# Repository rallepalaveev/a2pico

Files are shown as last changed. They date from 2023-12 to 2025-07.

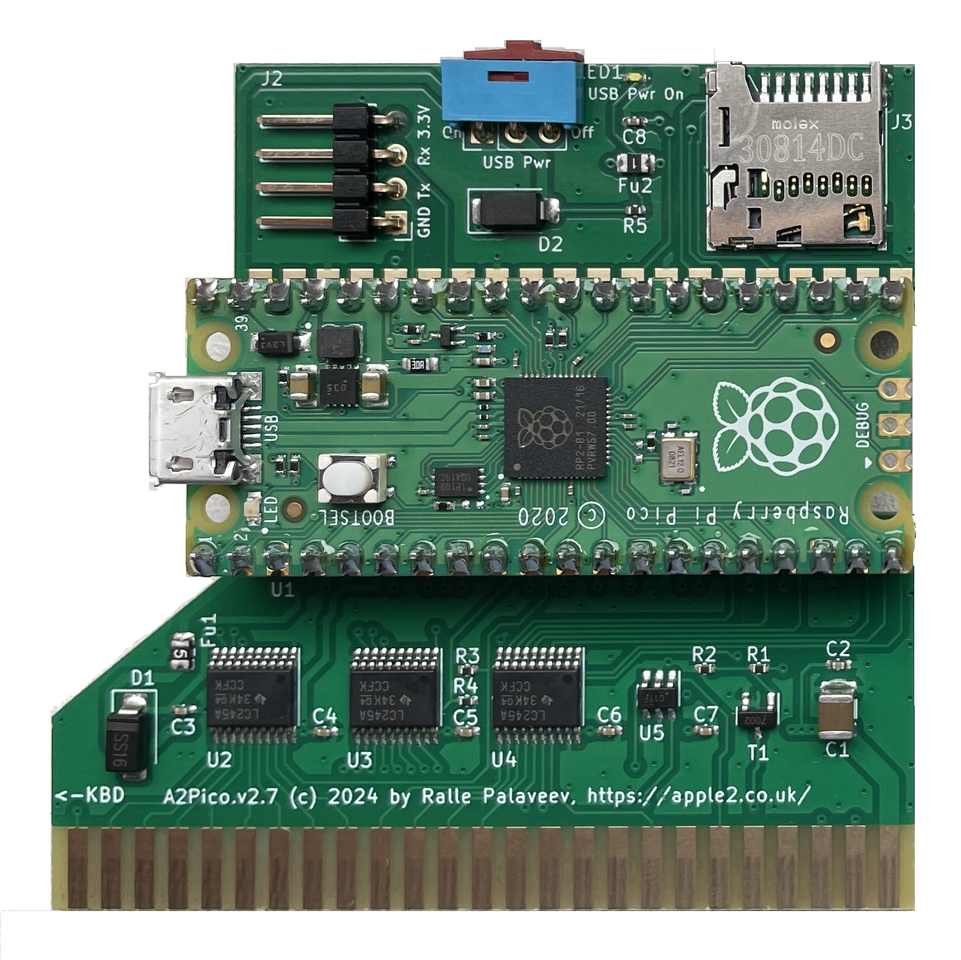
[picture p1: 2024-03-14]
A2Pico.v2.7/A2Pico.v2.7.png

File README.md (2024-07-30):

# A2Pico Reference Hardware

This repository is the home of the A2Pico reference hardware. Please refer to the upstream repository at https://github.com/oliverschmidt/a2pico for general information on A2Pico.

## Hardware Revision History

Version 1.4 is the innitial design with 3x 74LVC245 and 1x 74HC08 to prove the concept. However it is obsolete as it does not switch off the Expansion ROM ($C800-$CFFF), which is always available and could cause data bus conlisions if used with other cards that use this memory space.

Version 1.5 switches off the Expansion ROM ($C800-$CFFF) when $CFFF is accessed or when reset is issued, and switches it back on again when the slot memory is accessed (IOSelect).

Version 1.6 combines 3 of the logic chips into a PLD. 74LS08, 74LS133 and 74LS02 are replaced by ATF22V10.

The RPI usage is as follows:

| GPIO | Usage |
|:---|:---|
| 0 |  UART TX  |
| 1 |  UART RX  |
| 2 - 13  | A0 - A11  |
| 14 | R/W |
| 15 - 22 | D0 - D7 |
| 26 | ENBL |
| 27 | IRQ |
| 28 | RES |

Version "n" has support for a MicroSD card with **no** ExtROM capability.

The RPI usage of the "n" versions is as follows:

| GPIO | Usage |
|:---|:---|
| 0 |  SPI RX |
| 1 |  SPI CSn  |
| 2 |  SPI SCK  |
| 3 |  SPI TX |
| 4 |  NMI |
| 5 - 12  | A0 - A7 |
| 13 | DEVSEL |
| 14 | R/W |
| 15 - 22 | D0 - D7 |
| 26 | ENBL |
| 27 |  IRQ |
| 28 |  RES |

Version 1.7 is a direct successor of v1.4. Changes are replacing the 7408 by a 7411, data direction is controlled now by the Raspberry Pi Pico, which allows for all memory locations to be emulated, ENBL has an option to be is driven by a voltage divider for minimum latency, a USB "back power" option is included.

The RPI usage is as follows:

| GPIO | Usage |
|:---|:---|
| 0 |  UART TX  |
| 1 |  DATA dir |
| 2 - 13  | A0 - A11  |
| 14 | R/W |
| 15 - 22 | D0 - D7 |
| 26 | ENBL |
| 27 | IRQ |
| 28 | RES |

Versions 2.4 and 2.5 are a new hardware variant of v1.7 - TH and SMD respectively. The major change is that A0-7 and D0-7 are multiplexed and an SD card interface is added.
The RPI usage is as follows:

| GPIO | Usage |
|:---|:---|
| 0 |  UART Tx  |
| 1 |  UART Rx  |
| 2 |  ENBL |
| 3 - 10  | AD0 - AD7 |
| 11 - 14 | A8 - A11  |
| 15 | R/W |
| 16 | PHI1 |
| 17 | RES |
| 18 | IRQ |
| 19 | CMD |
| 20 | DAT0 |
| 21 | DAT3 |
| 22 | CLK |
| 26 | AL-OE |
| 27 | D-OE |
| 28 | DDIR |

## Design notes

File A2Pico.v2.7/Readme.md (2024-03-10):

A2Pico Version 2.7 is a follow-up of 2.5 with some small changes - changed form factor, added USB power slide switch, added USB power LED.

The RPI usage is as follows:

| GPIO | Usage |
|:---|:---|
| 0 |  UART Tx  |
| 1 |  UART Rx  |
| 2 |  ENBL |
| 3 - 10  | AD0 - AD7 |
| 11 - 14 | A8 - A11  |
| 15 | R/W |
| 16 | Ф1 |
| 17 | RES |
| 18 | IRQ |
| 19 | CMD |
| 20 | DAT0 |
| 21 | DAT3 |
| 22 | CLK |
| 26 | AL-OE |
| 27 | D-OE |
| 28 | DDIR |

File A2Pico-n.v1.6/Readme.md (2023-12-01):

This is a HW implementation with support for a MicroSD card and **no** ExtROM capability.

The pinout of the "n" versions is as follows:

| GPIO | Usage |
|:---|:---|
| 0 |  SPI RX |
| 1 |  SPI CSn  |
| 2 |  SPI SCK  |
| 3 |  SPI TX |
| 4 |  NMI |
| 5 - 12  | A0 - A7 |
| 13 | DEVSEL |
| 14 | R/W |
| 15 - 22 | D0 - D7 |
| 26 | ENBL |
| 27 |  IRQ |
| 28 |  RES |

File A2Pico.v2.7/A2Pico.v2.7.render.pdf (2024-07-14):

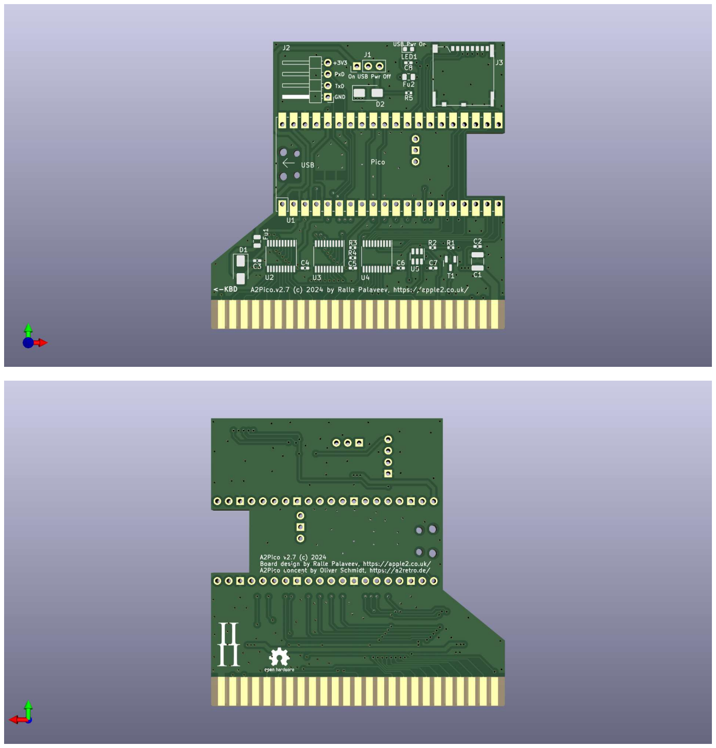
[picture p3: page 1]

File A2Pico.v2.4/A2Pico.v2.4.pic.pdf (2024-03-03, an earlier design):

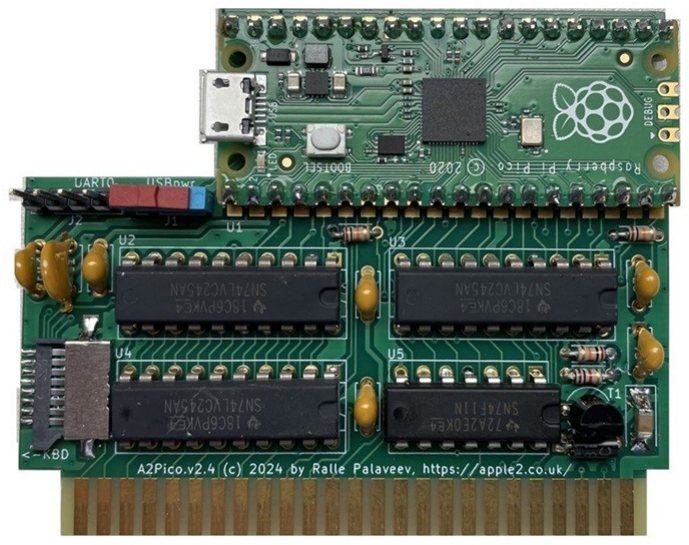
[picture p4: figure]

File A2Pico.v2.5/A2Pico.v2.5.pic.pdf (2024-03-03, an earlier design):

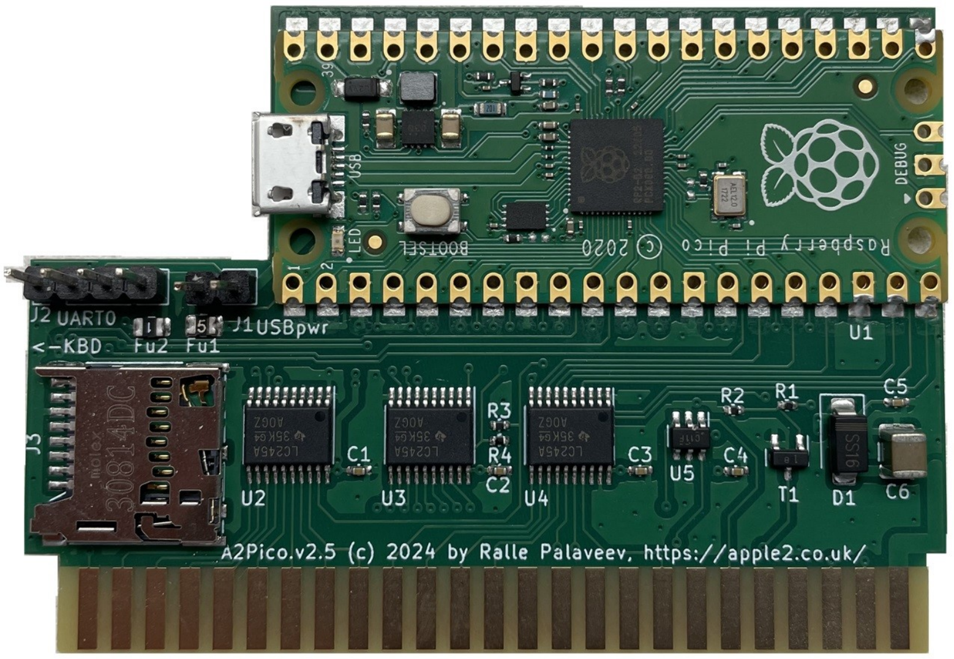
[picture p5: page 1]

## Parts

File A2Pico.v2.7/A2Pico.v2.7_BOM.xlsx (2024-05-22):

Comment | Designator | Footprint | JLCPCB Part #（optional）
10V 100uF X5R ±20% 1210 Multilayer Ceramic Capacitors MLCC - SMD/SMT ROHS | C1 | 1210 | C386065
16V 100nF X7R ±10% 0402 Multilayer Ceramic Capacitors MLCC - SMD/SMT ROHS | C2,C3,C4,C5,C6,C7,C8 | 0402 | C1525
1K | R1,R5 | 0402 | C11702
10K | R2,R3,R4 | 0402 | C25744
1.28mm Gold Deck MicroSD card (TF card) Self bomb SMD SD Card Connectors ROHS | J3 | SMD | C428492
3A Straight Square Pins 2.54mm 6mm -40℃~+105℃ 1 2 3mm 2.54mm Blac | J1 | PinHeader_1x02_P2.54mm_Vertical | C492401
3A Right-Angle Square Pins 2.5mm 4P 6mm | J2 | PinHeader_1x04_P2.54mm_Vertical | C2829875
6V 500mA Resettable Fuse | Fu1 | 0805-50 | C782729
6V 100mA Resettable Fuse | Fu2 | 0805 | C20975
SS16 SBD | D1,D2 | SMA(DO-214AC) | C908233
BS170F-BV | T1 | SOT-23 | C558098
Raspberry Pi PICO | U1 |  | C7203002
SN74LVC245APWR | U2,U3,U4 | TSSOP-20 | C7848
SN74LVC1G11DBVR | U5 | SOT-23-6 | C22046
White LED | LED1 | 0402 | C6848499

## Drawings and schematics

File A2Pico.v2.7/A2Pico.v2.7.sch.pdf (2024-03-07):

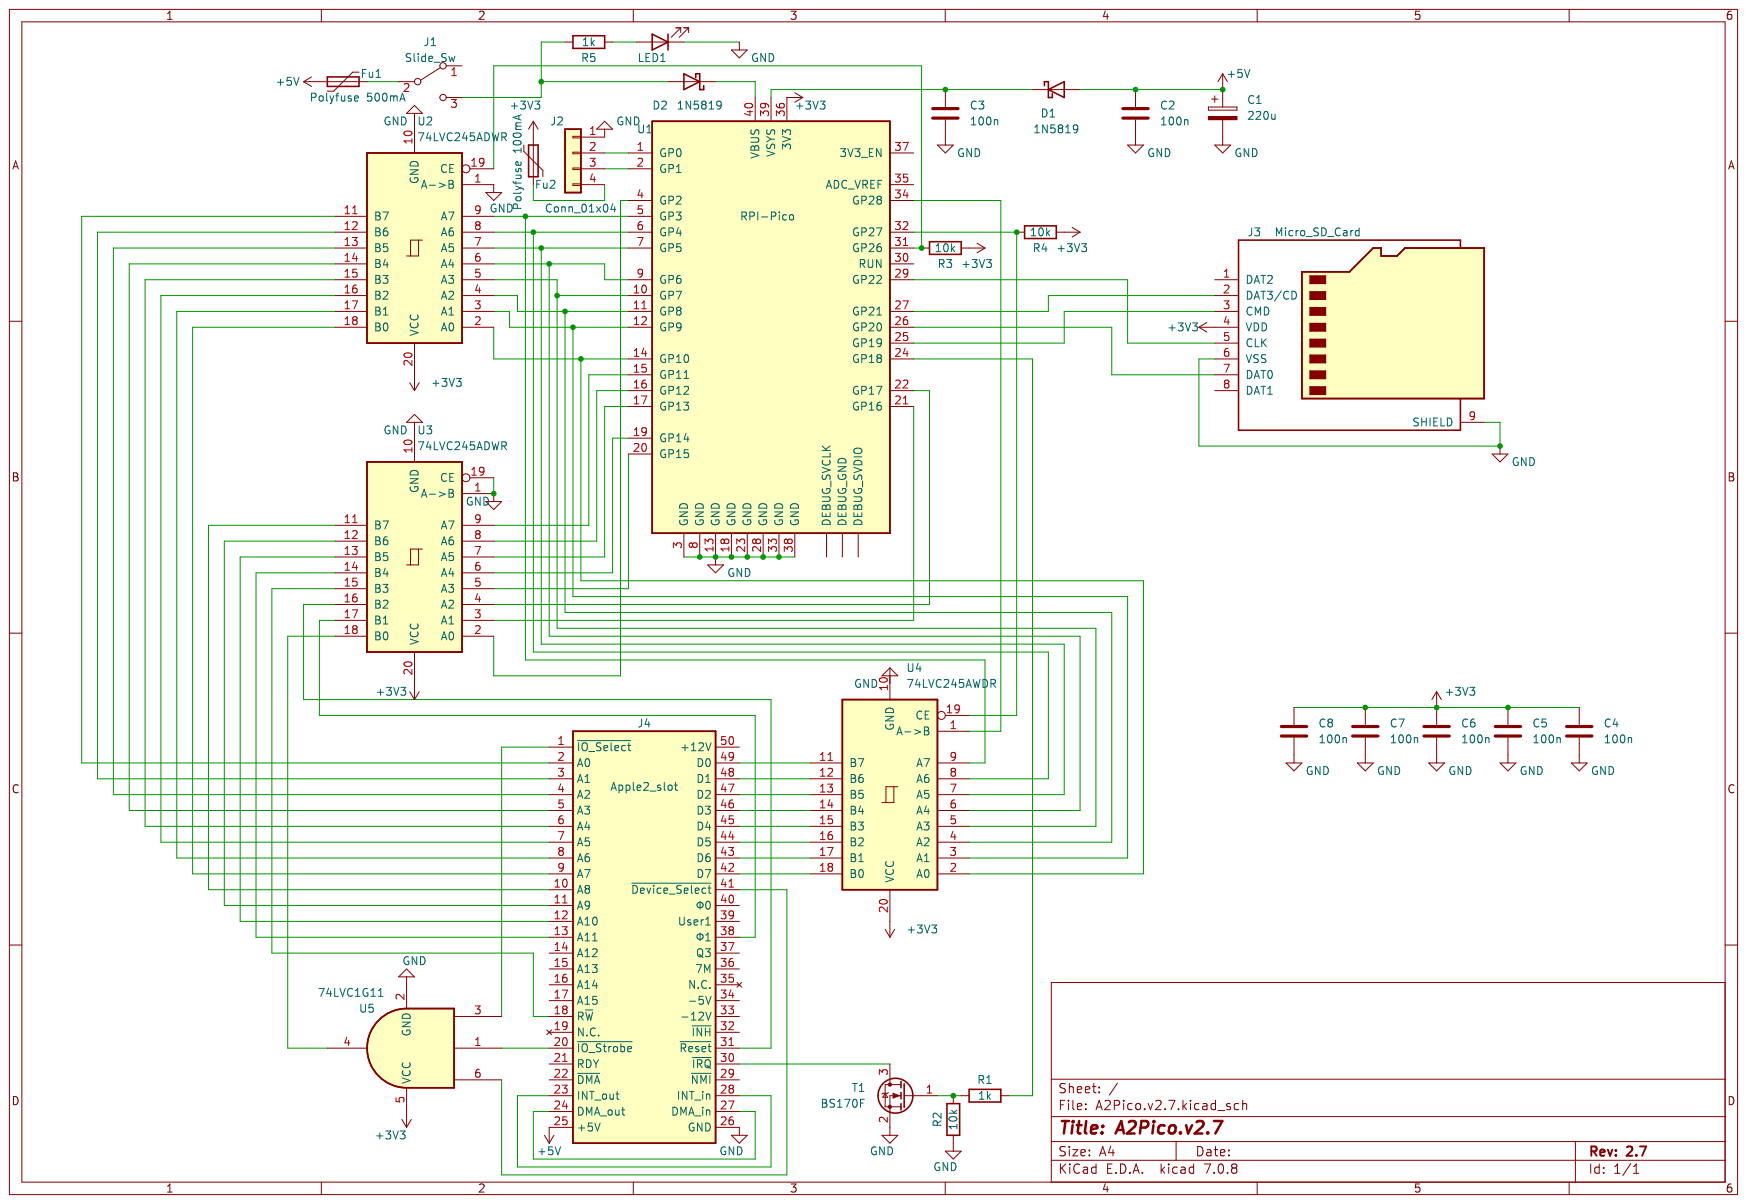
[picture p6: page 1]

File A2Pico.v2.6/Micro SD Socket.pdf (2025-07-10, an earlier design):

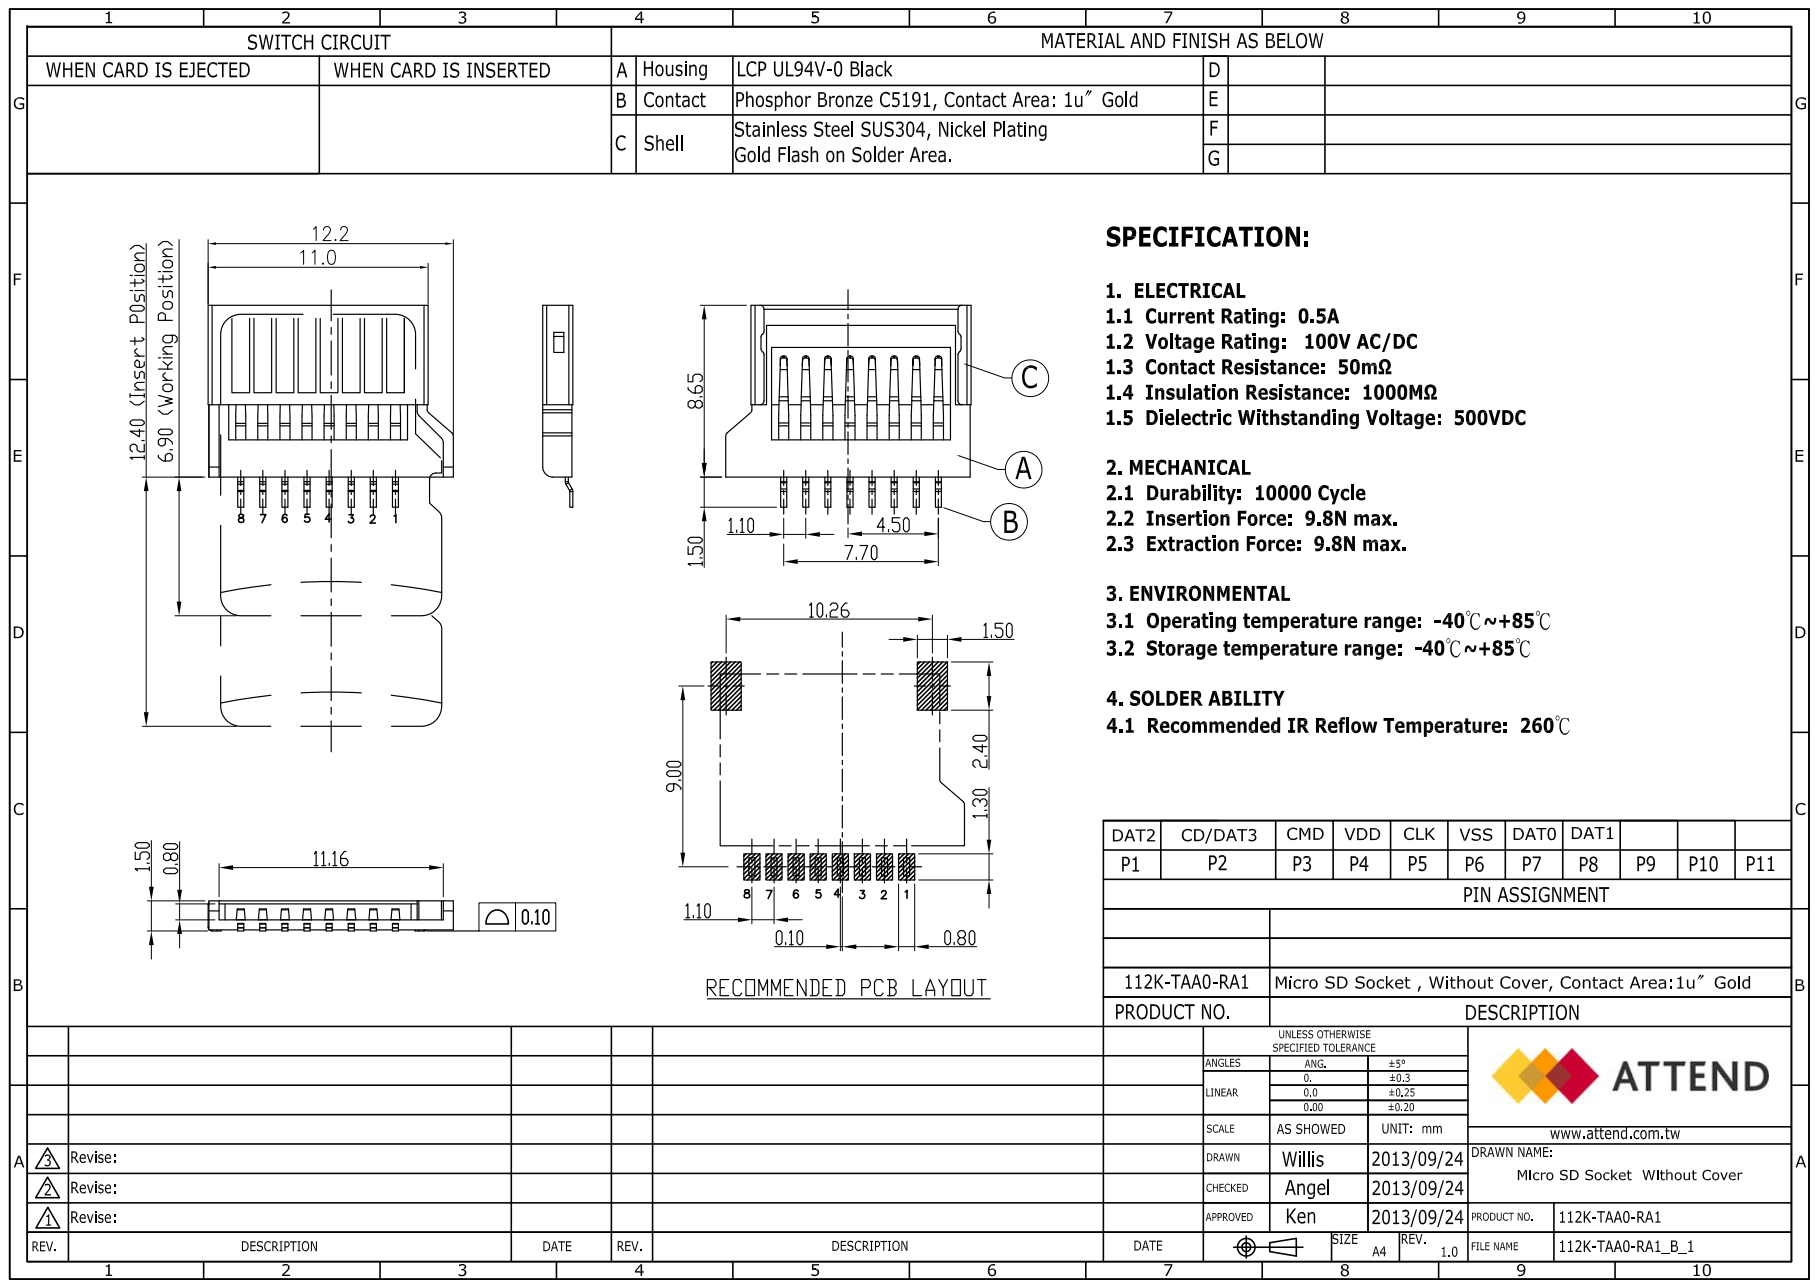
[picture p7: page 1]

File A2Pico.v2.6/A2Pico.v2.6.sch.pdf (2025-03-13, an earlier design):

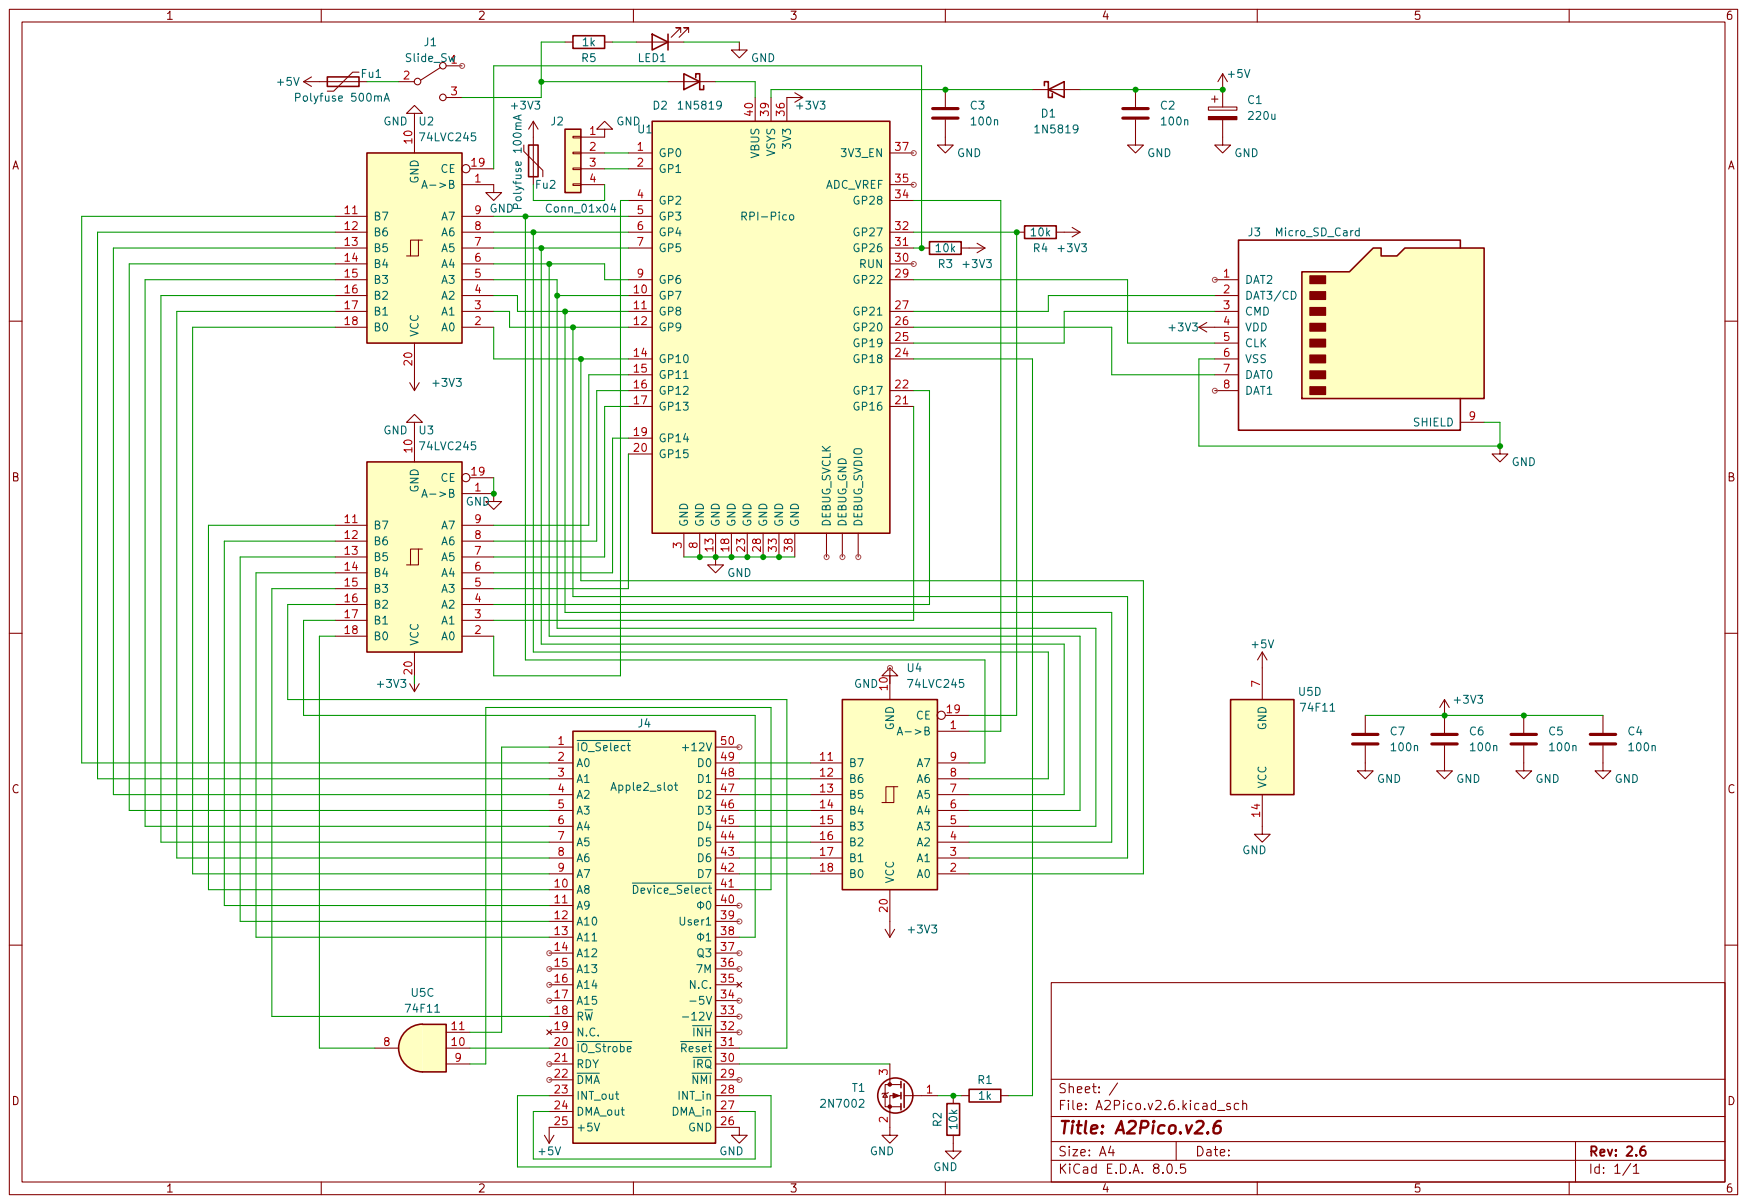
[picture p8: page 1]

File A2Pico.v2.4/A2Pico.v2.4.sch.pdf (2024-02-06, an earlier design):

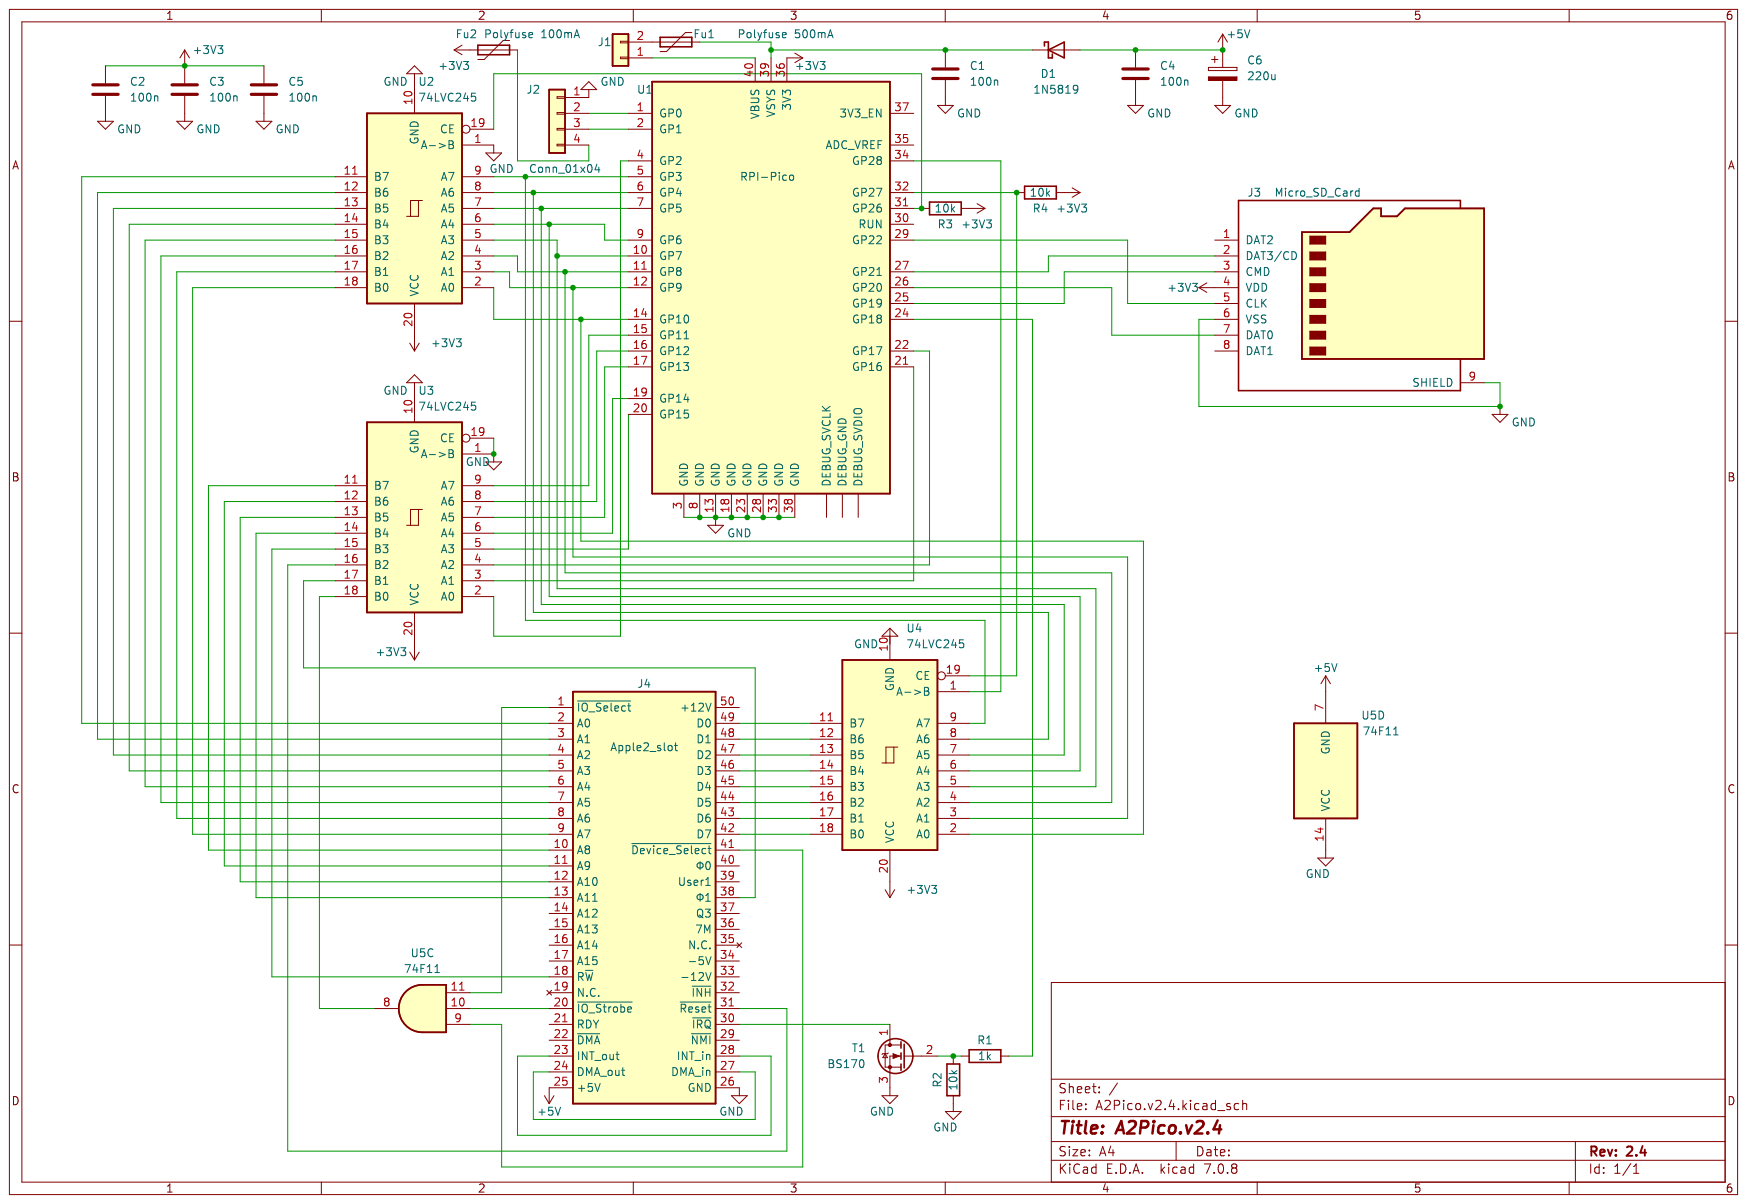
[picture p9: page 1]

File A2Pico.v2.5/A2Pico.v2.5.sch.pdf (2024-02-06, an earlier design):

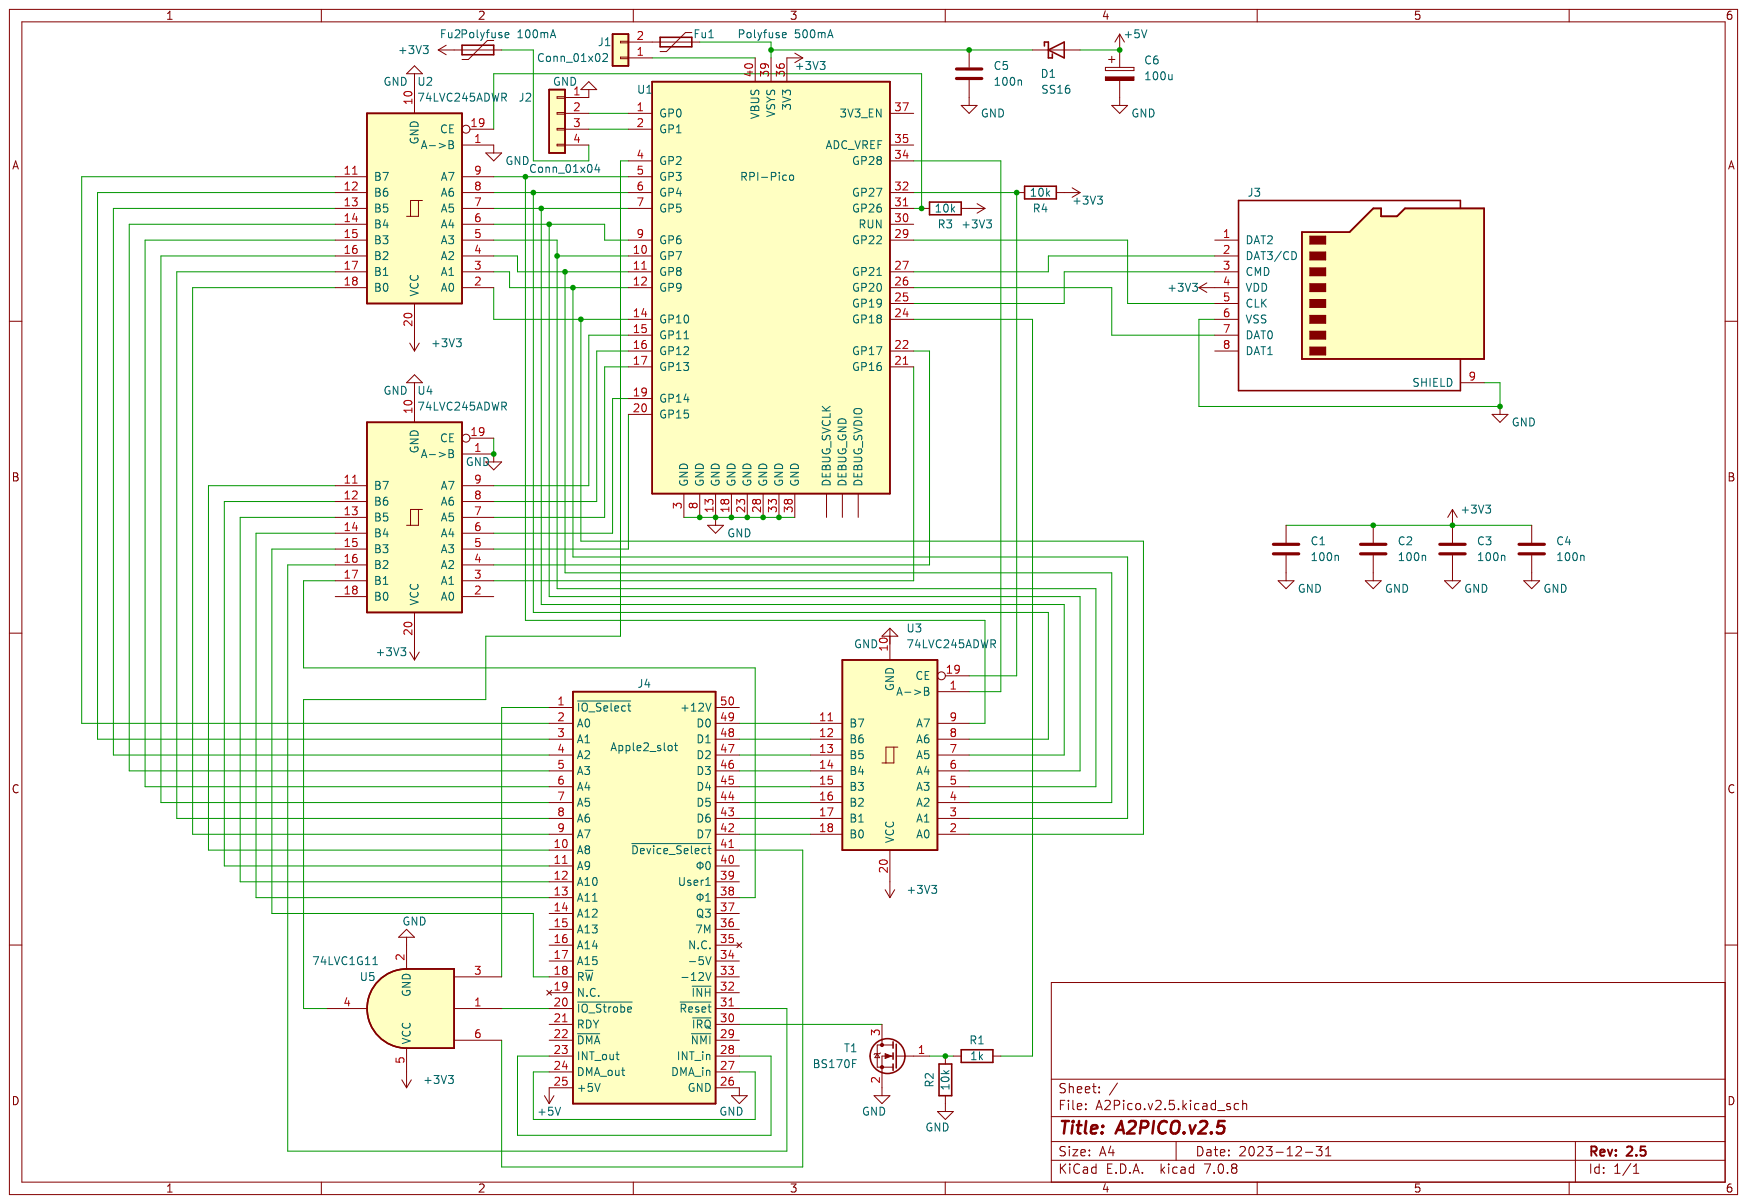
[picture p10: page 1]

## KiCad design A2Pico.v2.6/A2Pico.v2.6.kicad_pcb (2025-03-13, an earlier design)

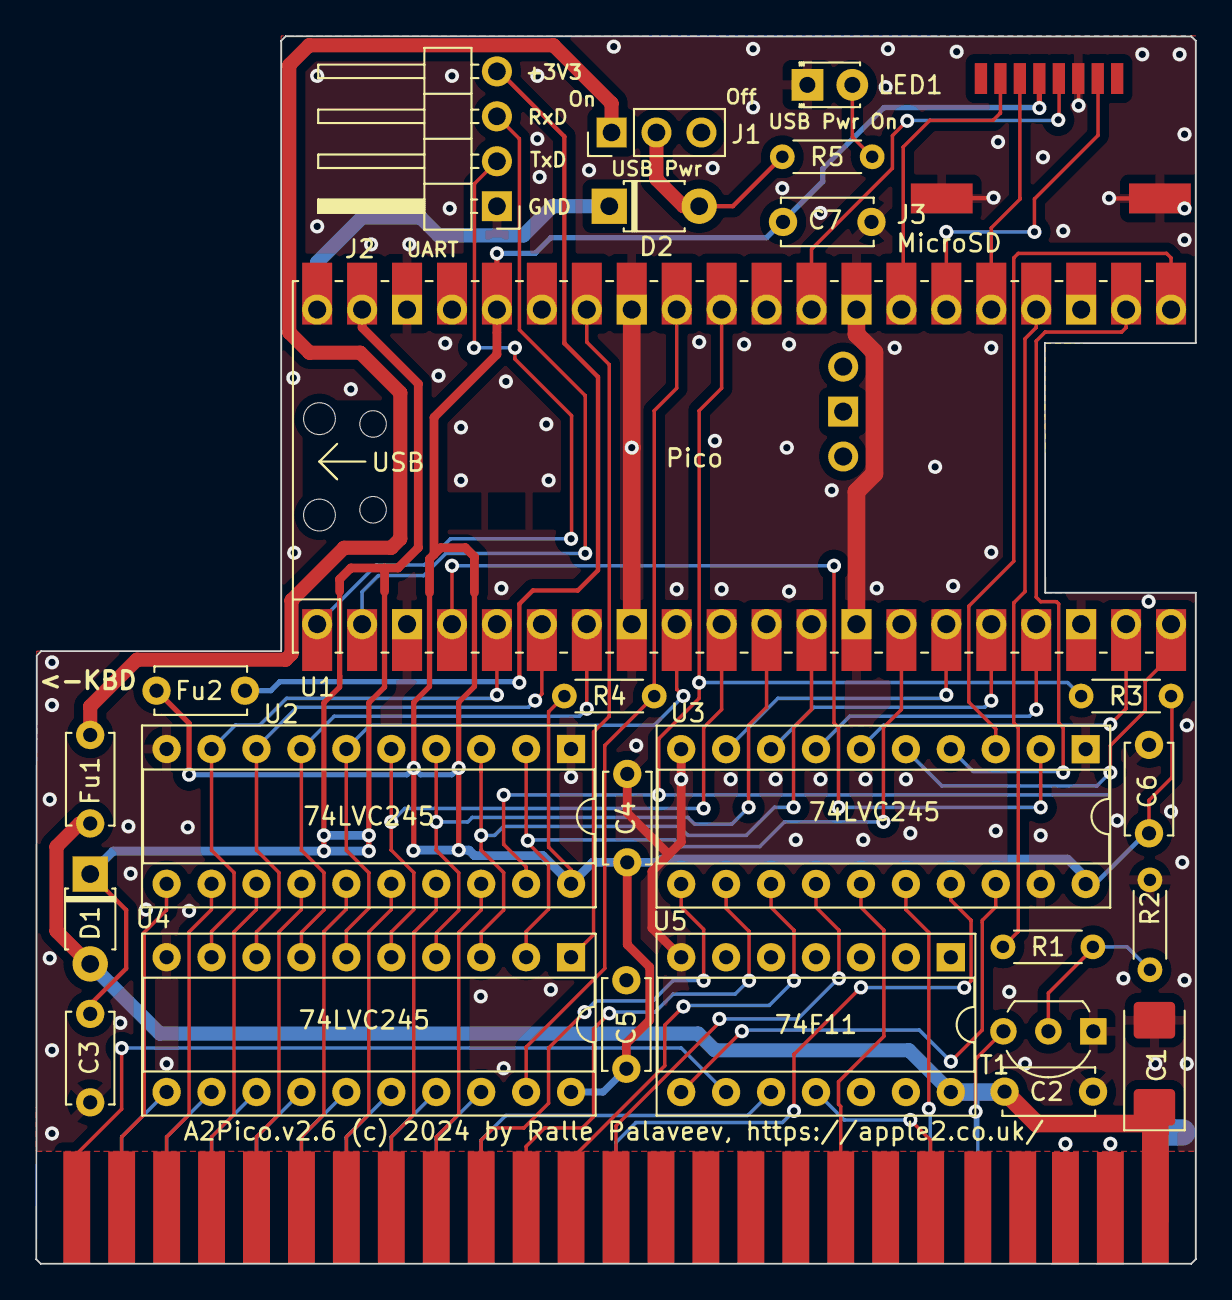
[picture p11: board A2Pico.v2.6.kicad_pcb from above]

Board: 2 copper layers, 65.5 x 69.4 mm, 25 parts (0 on the bottom side), 31 nets.

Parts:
C1: 220uF; CP_EIA-6032-15_Kemet-U
C2, C3, C4, C5, C6, C7: 100n; C_Disc_D5.0mm_W2.5mm_P5.00mm
D1, D2: D_T-1_P5.08mm_Horizontal
Fu1: 500mA; C_Disc_D5.0mm_W2.5mm_P5.00mm
Fu2: 100mA; C_Disc_D5.0mm_W2.5mm_P5.00mm
J1: PinHeader_1x03_P2.54mm_Vertical
J2: PinHeader_1x04_P2.54mm_Horizontal
LED1: LED_D1.8mm_W3.3mm_H2.4mm
R1, R5: 1k; R_Axial_DIN0204_L3.6mm_D1.6mm_P5.08mm_Horizontal
R2, R3, R4: 10k; R_Axial_DIN0204_L3.6mm_D1.6mm_P5.08mm_Horizontal
T1: TO-92L_Inline_Wide
U1: Pico / PicoW; RPi_PicoW_SMD_TH
U2, U3, U4: 74LVC245; DIP-20_W7.62mm_Socket
U5: 74F11; DIP-14_W7.62mm_Socket

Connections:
3.3V: C4.1, C5.1, C6.1, C7.1, Fu2.1, R3.1, R4.2, U1.36 (3V3), U2.20, U3.20, U4.20
3.3V_out: Fu2.2, J2.4
5V: C1.1, C2.2, D1.2, Fu1.1, U5.14
AL-OE: R3.2, U1.31 (GPIO26_ADC0), U2.19
D-Dir: U1.34 (GPIO28_ADC2), U4.1
D-OE: R4.1, U1.32 (GPIO27_ADC1), U4.19
ENBL: U3.18, U5.8
GND: C1.2, C2.1, C3.1, C4.2, C5.2, C6.2, C7.2, J2.1, LED1.1, R2.2, T1.1, U1.3 (GND), U1.8 (GND), U1.13 (GND), U1.18 (GND), U1.23 (GND), U1.28 (GND), U1.33 (AGND), U1.38 (GND), U2.1, U2.10, U3.1, U3.10, U3.19, U4.10, U5.7
J1-1: Fu1.2, J1.1
J1-2: D2.2, J1.2, R5.2
L-A8: U1.15 (GPIO11), U3.9
L-A9: U1.16 (GPIO12), U3.8
L-A10: U1.17 (GPIO13), U3.7
L-A11: U1.19 (GPIO14), U3.6
L-AD0: U1.5 (GPIO3), U2.9, U4.9
L-AD1: U1.6 (GPIO4), U2.8, U4.8
L-AD2: U1.7 (GPIO5), U2.7, U4.7
L-AD3: U1.9 (GPIO6), U2.6, U4.6
L-AD4: U1.10 (GPIO7), U2.5, U4.5
L-AD5: U1.11 (GPIO8), U2.4, U4.4
L-AD6: U1.12 (GPIO9), U2.3, U4.3
L-AD7: U1.14 (GPIO10), U2.2, U4.2
L-ENBL: U1.4 (GPIO2), U3.2
L-IRQ: R1.2, U1.24 (GPIO18)
L-PHI1: U1.21 (GPIO16), U3.3
L-RW: U1.20 (GPIO15), U3.5
L-Reset: U1.22 (GPIO17), U3.4
Rx: J2.3, U1.2 (GPIO1)
Tx: J2.2, U1.1 (GPIO0)
VBUS: D2.1, U1.40 (VBUS)
VSYS: C3.2, D1.1, U1.39 (VSYS)

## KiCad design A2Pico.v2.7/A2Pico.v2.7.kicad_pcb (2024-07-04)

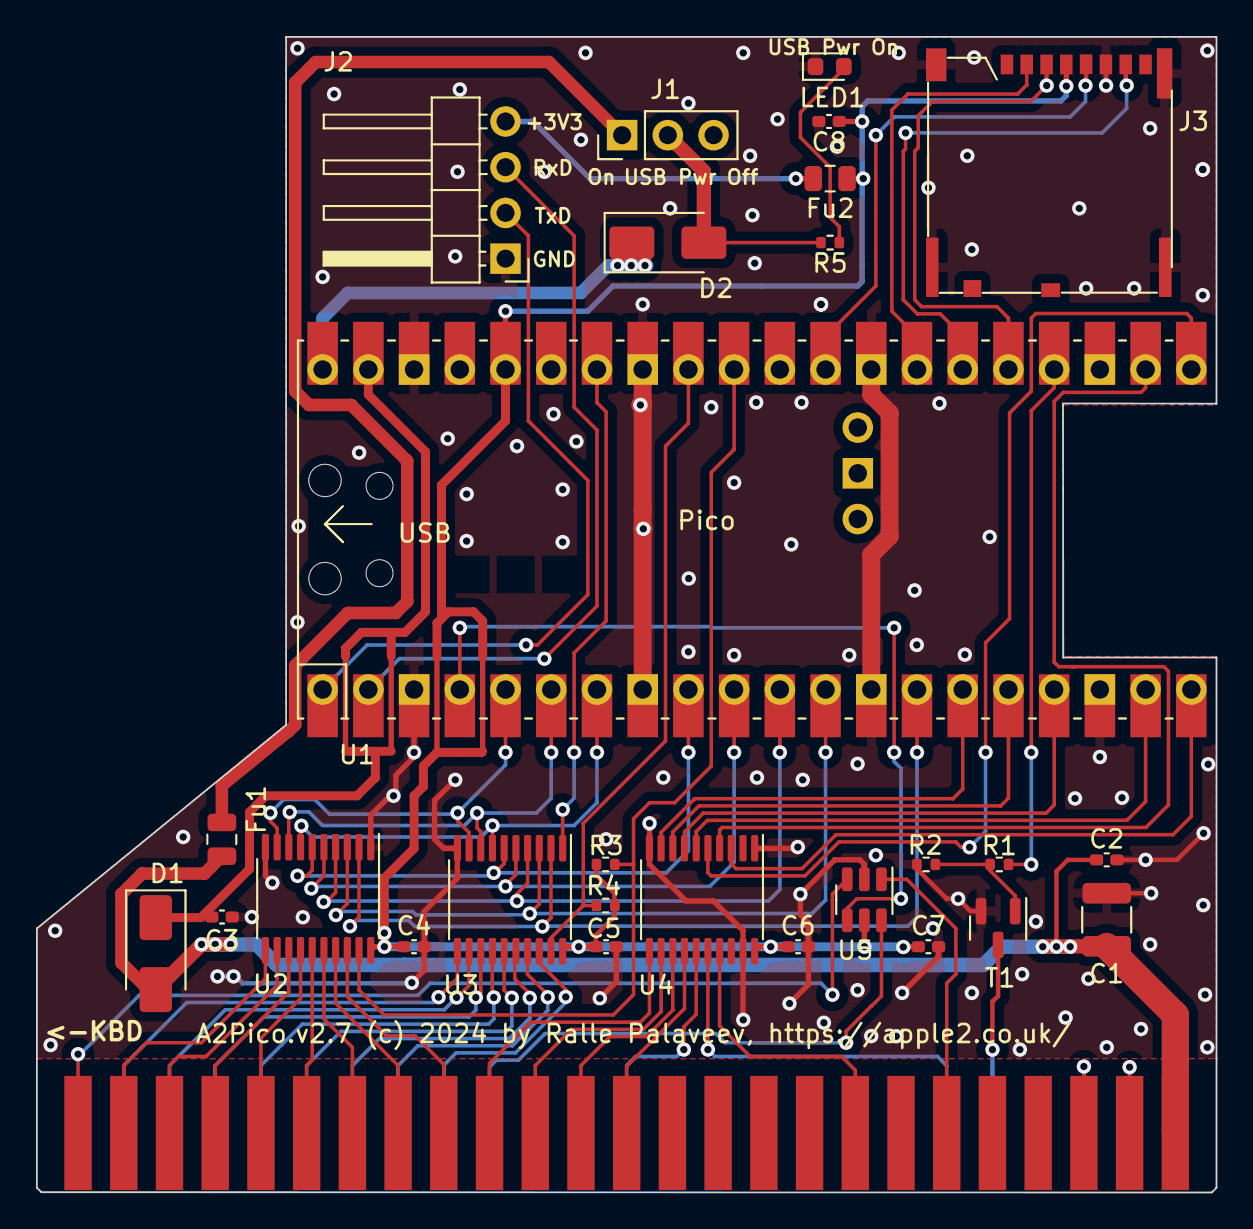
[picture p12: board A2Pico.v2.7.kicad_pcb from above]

Board: 2 copper layers, 65.5 x 64.2 mm, 27 parts (0 on the bottom side), 35 nets.

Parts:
C1: C_1210_3225Metric
C2, C3, C4, C5, C6, C7, C8: 100n; C_0402_1005Metric_Pad0.74x0.62mm_HandSolder
D1, D2: SS16; D_SMA
Fu1, Fu2: Fuse_0805_2012Metric
J1: PinHeader_1x03_P2.54mm_Vertical
J2: PinHeader_1x04_P2.54mm_Horizontal
J3: microSD_HC_Molex_104031-0811
LED1: LED_0603_1608Metric
R1, R5: 1k; R_0402_1005Metric
R2, R3, R4: 10k; R_0402_1005Metric
T1: BS170F-BV; SOT-23
U1: Pico; RPi_PicoW_SMD_TH
U2, U3, U4: SN74LVC245APWR; TSSOP-20_4.4x6.5mm_P0.65mm
U5: SN74LVC1G11DBVR; SOT-23-6

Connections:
3.3V: C4.1, C5.1, C6.1, C7.1, C8.2, Fu2.1, J3.4, R3.2, R4.1, U1.36 (3V3), U2.20, U3.20, U4.20, U5.5
3.3V_out: Fu2.2, J2.4
5V: C1.1, C2.1, D1.2, Fu1.2
AL-OE: R3.1, U1.31 (GPIO26_ADC0), U2.19
CLK: J3.5, U1.29 (GPIO22)
CMD: J3.3, U1.25 (GPIO19)
D-Dir: U1.34 (GPIO28_ADC2), U3.1
D-OE: R4.2, U1.32 (GPIO27_ADC1), U3.19
DAT0: J3.7, U1.26 (GPIO20)
DAT3: J3.2, U1.27 (GPIO21)
ENBL: U1.4 (GPIO2), U5.4
GND: C1.2, C2.2, C3.2, C4.2, C5.2, C6.2, C7.2, C8.1, J2.1, J3.6, J3.11, LED1.1, R2.2, T1.2, U1.3 (GND), U1.8 (GND), U1.13 (GND), U1.18 (GND), U1.23 (GND), U1.28 (GND), U1.33 (AGND), U1.38 (GND), U2.1, U2.10, U3.10, U4.1, U4.10, U4.19, U5.2
J1-1: Fu1.1, J1.1
J1-2: D2.2, J1.2, R5.2
L-A8: U1.15 (GPIO11), U4.9
L-A9: U1.16 (GPIO12), U4.8
L-A10: U1.17 (GPIO13), U4.7
L-A11: U1.19 (GPIO14), U4.6
L-AD0: U1.5 (GPIO3), U2.9, U3.9
L-AD1: U1.6 (GPIO4), U2.8, U3.8
L-AD2: U1.7 (GPIO5), U2.7, U3.7
L-AD3: U1.9 (GPIO6), U2.6, U3.6
L-AD4: U1.10 (GPIO7), U2.5, U3.5
L-AD5: U1.11 (GPIO8), U2.4, U3.4
L-AD6: U1.12 (GPIO9), U2.3, U3.3
L-AD7: U1.14 (GPIO10), U2.2, U3.2
L-IRQ: R1.1, U1.24 (GPIO18)
L-PHI: U1.21 (GPIO16), U4.5
L-RW: U1.20 (GPIO15), U4.3
L-Reset: U1.22 (GPIO17), U4.4
Rx: J2.3, U1.2 (GPIO1)
Tx: J2.2, U1.1 (GPIO0)
VBUS: D2.1, U1.40 (VBUS)
VSYS: C3.1, D1.1, U1.39 (VSYS)
m-IRQ: R1.2, R2.1, T1.1

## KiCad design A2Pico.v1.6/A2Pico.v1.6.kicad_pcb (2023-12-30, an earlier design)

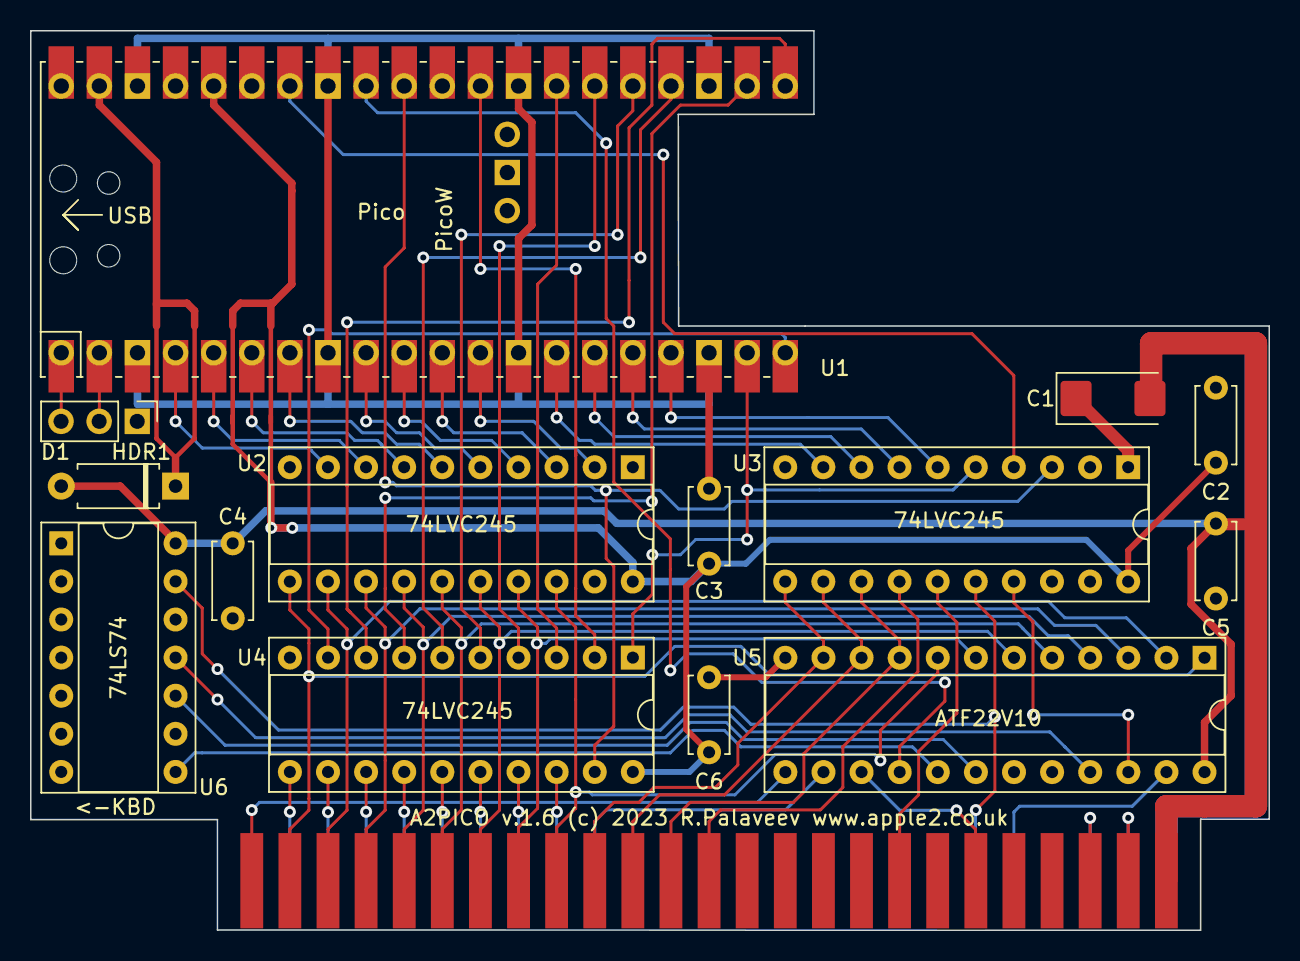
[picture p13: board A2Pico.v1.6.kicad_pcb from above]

Board: 2 copper layers, 82.5 x 60.0 mm, 14 parts (0 on the bottom side), 4 nets.

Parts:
C1: 220uF; CP_EIA-6032-15_Kemet-U
C2, C3, C4, C5, C6: 100n; C_Disc_D5.0mm_W2.5mm_P5.00mm
D1: D_A-405_P7.62mm_Horizontal
HDR1: PinHeader_1x03_P2.54mm_Vertical
U1: PicoW; RPi_PicoW_SMD_TH
U2, U3, U4: 74LVC245; DIP-20_W7.62mm_Socket
U5: ATF22V10; DIP-24_W7.62mm_Socket
U6: 74LS74; DIP-14_W7.62mm_Socket

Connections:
3.3V: C2.1, C3.1, C6.1, U1.36 (3V3), U2.20, U3.20, U4.20
5V: C1.2, C4.2, C5.2, D1.2, U5.24, U6.14
GND: C1.1, C2.2, C3.2, C4.1, C5.1, C6.2, HDR1.1, U1.3 (GND), U1.8 (GND), U1.13 (GND), U1.18 (GND), U1.23 (GND), U1.28 (GND), U1.33 (AGND), U1.38 (GND), U2.1, U2.10, U2.19, U3.1, U3.10, U3.19, U4.10, U5.12, U6.2, U6.7, U6.12
VSYS: D1.1, U1.39 (VSYS)

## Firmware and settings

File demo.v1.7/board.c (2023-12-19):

/*

MIT License

Copyright (c) 2022 Oliver Schmidt (https://a2retro.de/)

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
*/

#include "bus.pio.h"

#include "board.h"

extern const __attribute__((aligned(4))) uint8_t firmware[];

volatile bool active;

void __time_critical_func(board)(void) {
    for (uint gpio = gpio_addr; gpio < gpio_addr + size_addr; gpio++) {
        gpio_init(gpio);
        gpio_set_pulls(gpio, false, false);  // floating
    }

    for (uint gpio = gpio_data; gpio < gpio_data + size_data; gpio++) {
        pio_gpio_init(pio0, gpio);
        gpio_set_pulls(gpio, false, false);  // floating
    }

    gpio_init(gpio_enbl);
    gpio_set_pulls(gpio_enbl, false, false);  // floating

    pio_gpio_init(pio0, gpio_dir);
    pio_sm_set_pindirs_with_mask(pio0, sm_dir, 1ul << gpio_dir, 1ul << gpio_dir);
    pio_sm_set_pins_with_mask(   pio0, sm_dir, 0,               1ul << gpio_dir);

    uint offset;

    offset = pio_add_program(pio0, &enbl_program);
    enbl_program_init(offset);

    offset = pio_add_program(pio0, &write_program);
    write_program_init(offset);

    offset = pio_add_program(pio0, &read_program);
    read_program_init(offset);

    offset = pio_add_program(pio0, &dir_program);
    dir_program_init(offset);

    active = false;

    while (true) {
        uint32_t enbl = pio_sm_get_blocking(pio0, sm_enbl);
        uint32_t addr = enbl & 0x0FFF;
        uint32_t io   = enbl & 0x0F00;  // IOSTRB or IOSEL
        uint32_t strb = enbl & 0x0800;  // IOSTRB
        uint32_t read = enbl & 0x1000;  // R/W

        if (read) {
            if (!io) {  // DEVSEL
                switch (addr & 0xF) {
                    case 0x0:
                        pio_sm_put(pio0, sm_read, sio_hw->fifo_rd);
                        break;
                    case 0x1:
                        // SIO_FIFO_ST_VLD_BITS _u(0x00000001)
                        // SIO_FIFO_ST_RDY_BITS _u(0x00000002)
                        pio_sm_put(pio0, sm_read, sio_hw->fifo_st << 6);
                        break;
                }
            } else {
                if (!strb || (active && (addr != 0x0FFF))) {
                    pio_sm_put(pio0, sm_read, firmware[addr]);
                }
            }
        } else {
            uint32_t data = pio_sm_get_blocking(pio0, sm_write);
            if (!io) {  // DEVSEL
                switch (addr & 0xF) {
                    case 0x0:
                        sio_hw->fifo_wr = data;
                        break;
                    case 0x1:
                        gpio_set_dir(gpio_irq, GPIO_IN);
                        break;
                }
            }
        }

        if (io && !strb) {
            active = true;
        } else if (addr == 0x0FFF) {
            active = false;
        }
    }
}

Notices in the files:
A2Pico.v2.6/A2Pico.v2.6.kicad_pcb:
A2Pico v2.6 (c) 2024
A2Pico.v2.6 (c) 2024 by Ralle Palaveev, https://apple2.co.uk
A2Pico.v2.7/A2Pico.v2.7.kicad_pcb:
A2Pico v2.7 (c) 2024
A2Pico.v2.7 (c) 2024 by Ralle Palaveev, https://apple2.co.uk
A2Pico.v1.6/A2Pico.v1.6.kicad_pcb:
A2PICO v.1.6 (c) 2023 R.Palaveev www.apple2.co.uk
